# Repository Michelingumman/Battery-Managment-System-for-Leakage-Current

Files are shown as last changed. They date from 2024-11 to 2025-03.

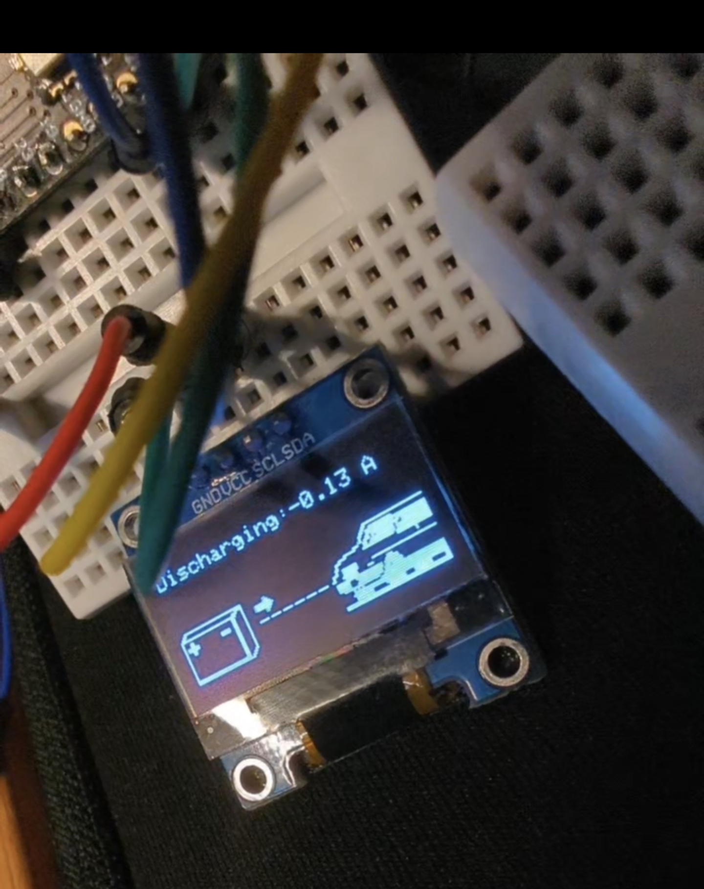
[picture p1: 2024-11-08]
rapport/screen.png

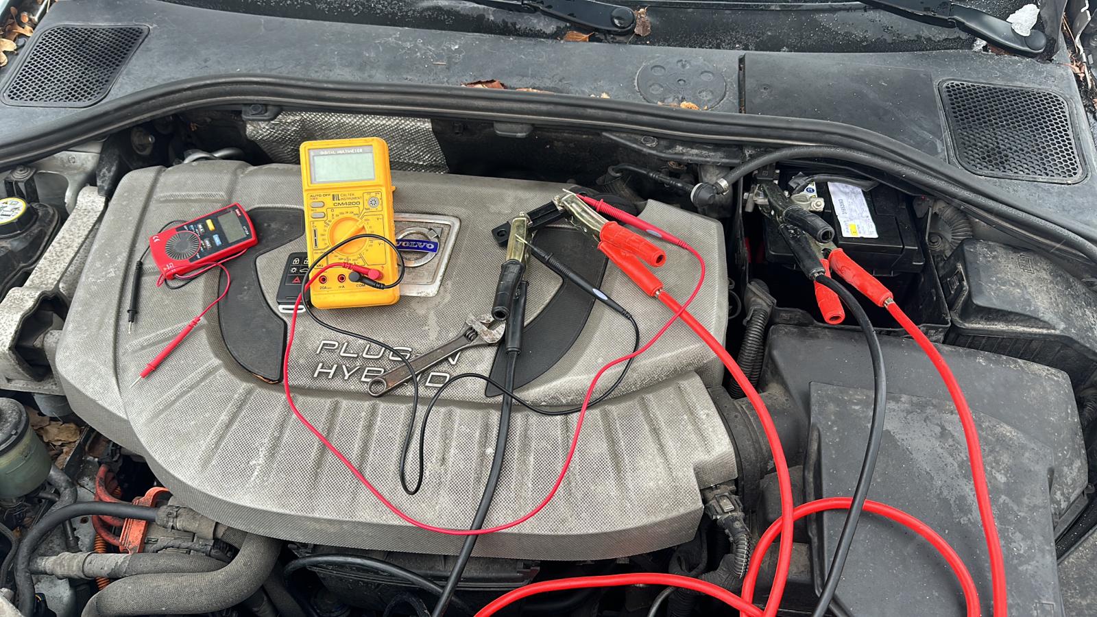
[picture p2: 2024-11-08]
rapport/test-setup.jpg

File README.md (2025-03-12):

<div align="center">
  <h1>🔋 ESP32 Battery Management System 🔌</h1>
  <p><em>A comprehensive solution for monitoring battery performance with wireless connectivity, data logging, and real-time analysis</em></p>

  <p>
    
    
    
    
  </p>
</div>

<div align="center">
  <table>
    <tr>
      <td width="70%">
        MQTT Dashboard
        <p align="center"><strong>MQTT Dashboard</strong> - Real-time monitoring</p>
      </td>
      <td width="50%">
        System Overview
        <p align="center"><strong>Added Display</strong> - Intuative animation</p>
      </td>
    </tr>
  </table>
</div>

<p align="center">
  OLED Display
  <br>
  <em>Plotted data</em>
</p>
<p align="center">
  OLED Display
  <br>
  <em>Web UI for accessing local SD card with delete and download availability</em>
</p>

---

## ✨ Features

- **📊 High-Precision Measurements**: Uses ADS1115 16-bit ADC for accurate voltage and current readings
- **💾 Data Logging**: Automatically records measurements to SD card with timestamps
- **🌐 Enhanced Web Interface**: Access, view, and manage data files with improved file browser and deletion capabilities
- **📡 Real-Time MQTT**: Publishes data points to MQTT broker for remote monitoring
- **🔄 OTA Updates**: Update firmware wirelessly through web interface
- **📱 Optional Display**: OLED display support for direct status viewing (configurable)

## 🛠️ Hardware Requirements

<div align="center">
  <table>
    <tr>
      <td align="center"><b>Component</b></td>
      <td align="center"><b>Purpose</b></td>
    </tr>
    <tr>
      <td>ESP32 Development Board</td>
      <td>Main controller with WiFi capability</td>
    </tr>
    <tr>
      <td>ADS1115 16-bit ADC Module</td>
      <td>High-precision analog-to-digital conversion</td>
    </tr>
    <tr>
      <td>DS3231 RTC Module</td>
      <td>Accurate timestamping of measurements</td>
    </tr>
    <tr>
      <td>SD Card Module</td>
      <td>Data storage and logging</td>
    </tr>
    <tr>
      <td>Current Shunt (100A/75mV)</td>
      <td>Current measurement</td>
    </tr>
    <tr>
      <td>SSD1306 OLED Display (Optional)</td>
      <td>Real-time data visualization</td>
    </tr>
  </table>
</div>

## 📚 Software Dependencies

- **Arduino IDE** with ESP32 support
- **Libraries**:
  - `WiFi`, `AsyncTCP`, `ESPAsyncWebServer` - Network connectivity
  - `SdFat` - SD card file operations
  - `RTClib` - RTC module interface
  - `Adafruit_ADS1X15` - ADC interface
  - `PubSubClient` - MQTT functionality
  - `ElegantOTA` - Over-the-air updates
  - `Adafruit_GFX` and `Adafruit_SSD1306` - Display support (if enabled)

## 🚀 Setup

1. **Create a `secrets.h` file** with your credentials:
   ```cpp
   #define WIFI_SSID "your_wifi_ssid"
   #define WIFI_PASS "your_wifi_password"
   #define MQTT_SERVER "your_mqtt_broker_address"
   #define MQTT_PORT 1883
   #define MQTT_USER "your_mqtt_username"
   #define MQTT_PASS "your_mqtt_password"
   ```

2. **Connect hardware components** according to pinout defined in code
3. **Upload the firmware** to ESP32

## 📖 Usage

### 📊 Data Collection
- The system automatically logs current and voltage data to SD card
- Data files are named `Amps YYYY-MM-DD.txt` and `Volts YYYY-MM-DD.txt`
- Each line contains timestamped measurements in the format `HH:MM:SS --> value1, value2, ...`

### 🌐 Improved Web Interface
1. Connect to the same WiFi network as ESP32
2. Navigate to `http://<ESP32_IP_ADDRESS>/` to access the file browser
3. Features:
   - **View Files**: Click the "View" button to see file contents directly in browser
   - **Delete Files**: Safely remove files with confirmation dialog
   - **Directory Navigation**: Browse folders with intuitive path display
   - **File Information**: See file sizes in human-readable format
   - **Quick Access**: One-click access to OTA updates with prominent button
4. Access OTA update page at `http://<ESP32_IP_ADDRESS>/update`

### 📡 MQTT Monitoring
The system publishes to three MQTT topics:

1. `battery/data/current` - Real-time current measurements
2. `battery/data/voltage` - Real-time voltage measurements 
3. `battery/status` - Connection status with device IP address

Message format (JSON):
```json
{
  "timestamp": "2024-06-03 14:35:22",
  "current": 0.123,
  "voltage": 12.45
}
```

## ⚙️ Configuration

Key parameters can be adjusted in the code:
- WiFi reconnection interval
- MQTT topic names
- Display settings
- SD card pins

## 📄 License

MIT License

## 🙏 Acknowledgments

- Thanks to all libraries and their contributors
- Inspired by various battery monitoring projects

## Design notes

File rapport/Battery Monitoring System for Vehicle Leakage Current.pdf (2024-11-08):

# Battery Monitoring System for Vehicle Leakage Current

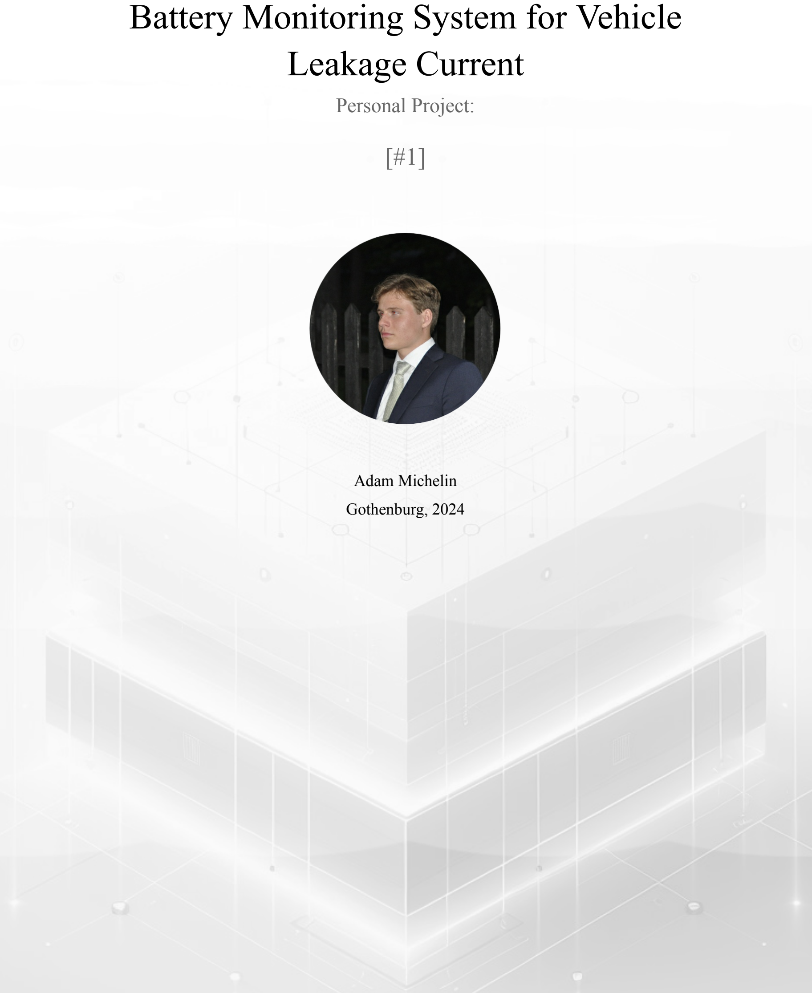
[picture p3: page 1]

### Personal Project:

[#1]

Adam Michelin
Gothenburg, 2024

## Abstract

The Battery Monitoring System (BMS) developed for monitoring vehicle leakage current presents a promising solution to the challenges of unexpected battery discharging. This report outlines the development process, including the rationale, methodology, components used, and measurement principles. Results from initial tests, along with discussions on the system's effectiveness and comparisons with other diagnostics tools, are provided. The report concludes with recommendations for future improvements and the significance of this project as a prototype for troubleshooting automotive electrical issues. It is worth noting that this project is a proof of concept undertaken for personal interest, aimed at enhancing understanding in electrical engineering and broadening personal project experiences.

## 1. Introduction

Upon encountering repeated instances of the starter battery in a family member's car being depleted after just 2 days of non-use, the need to investigate and rectify the underlying cause became paramount. Despite seeking assistance from a reputable service center, the persistent issue of unexplained and continuous battery discharge remained unresolved.

The starter battery, with a capacity of approximately 70Ah, should ideally hold a charge for at least some weeks under normal conditions. However, its complete depletion within 48 hours indicates an average draw of about 1.5 Amperes, meaning a persistent and unexplained drain on the system is occurring when the car is left unused.

Facing these challenges and the limitations of help from the service center, a proactive fix was developed: a Battery Monitoring System (BMS). This electrical device, designed to be compact, does a few key things. It keeps an eye on how much current the battery is using both the charging and discharging cycles, stores that data, and then shows it visually for analysis. The idea is to track the power usage over time in different situations and environments, hoping to find out why the battery keeps draining. This data-driven approach not only helps the troubleshooting but also gives solid evidence to explore new strategies if the usual fixes don't do the trick.

## 2. Material & Method

### 2.1 Vehicle and Battery Information

The vehicle under study is a "Volvo V60 D6 Plug-in Hybrid 2013" equipped with a 70Ah starter battery.

### 2.2 Components Used

The measurement device comprises the following components:
- ESP32 (WEMOS LOLIN D32, Espressif).
- DS3231 module (Real Time Clock).
- SD card reader module (SPI communication).
- Adafruit ADS1115 (16bit, Analog-Digital-Converter module).
- Shunt Resistor (75mV = 50A).
- Adafruit_SSD1306 (128x64 OLED display)

### 2.3 Libraries and Programming:

The necessary libraries for ESP32 programming include:

- Arduino.h
- Wire.h
- Adafruit_GFX
- Adafruit_SSD1306.h
- image_data.h (custom library)
- SPI.h
- SdFAT.h
- RTClib.h
- string.h

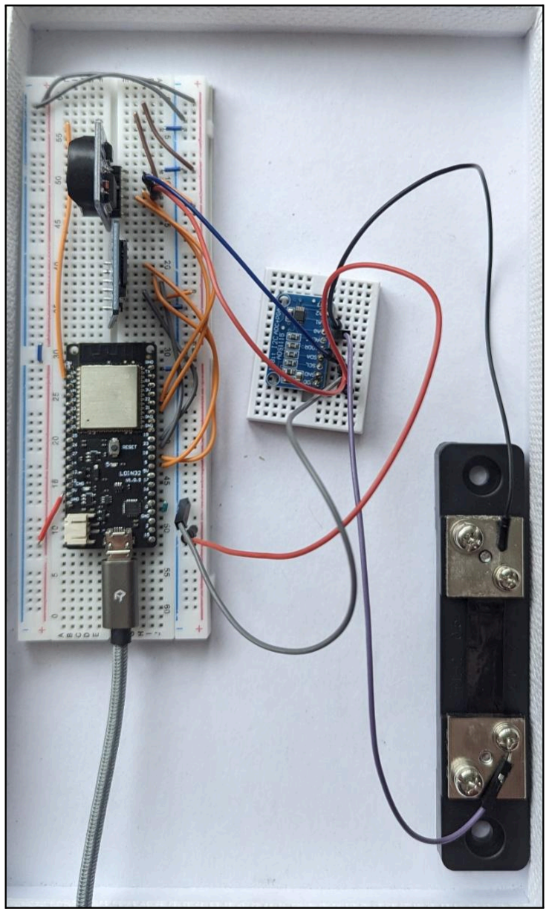
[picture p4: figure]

- Adafruit_ADS1X15.h | Figure 1, prototype on breadboard

The ESP32 was programmed using PlatformIO in Microsoft's Visual Studio Code (VS Code), enabling board configuration, programming, and debugging for various microcontrollers.

### 2.4 Electrical Setup:

The electrical circuit was initially prototyped on a breadboard for ease of debugging and testing flexibility with other modules. The final product remains on a breadboard but may transition to a custom PCB or other form based on the owner's preferences.

### 2.5 Measurement Principle:

The measurement device primarily monitors the voltage drop across the shunt resistor, which is strategically low in resistance to minimize its impact on the car's battery circuit and current flow. This voltage drop is measured and amplified through a 16-bit ADC for enhanced resolution. Without the 16-bit ADC, the voltage would be converted via the built in 12-bit ADC on the ESP32. The current resolution would then be too low, measuring steps of only 12mA, changing to a 16-bit ADC gives us the resolution of 0.7mA which is subjectively chosen to measure even the smallest current changes to better understand the underlying problem to the discharging.

### 2.6 Data Collection and Analysis:

The ESP32, with the assistance of the RTC and SD card reader, stores voltage readings every second and converts them into actual current values based on the calculated resolution. This data is then organized into minute-based arrays and stored on the SD card for further analysis. A Python script is used for visualizing this data in graph format, aiding in the interpretation of battery current over time.

## 3.Results

### 3.1 First Graph of Monitored Battery System

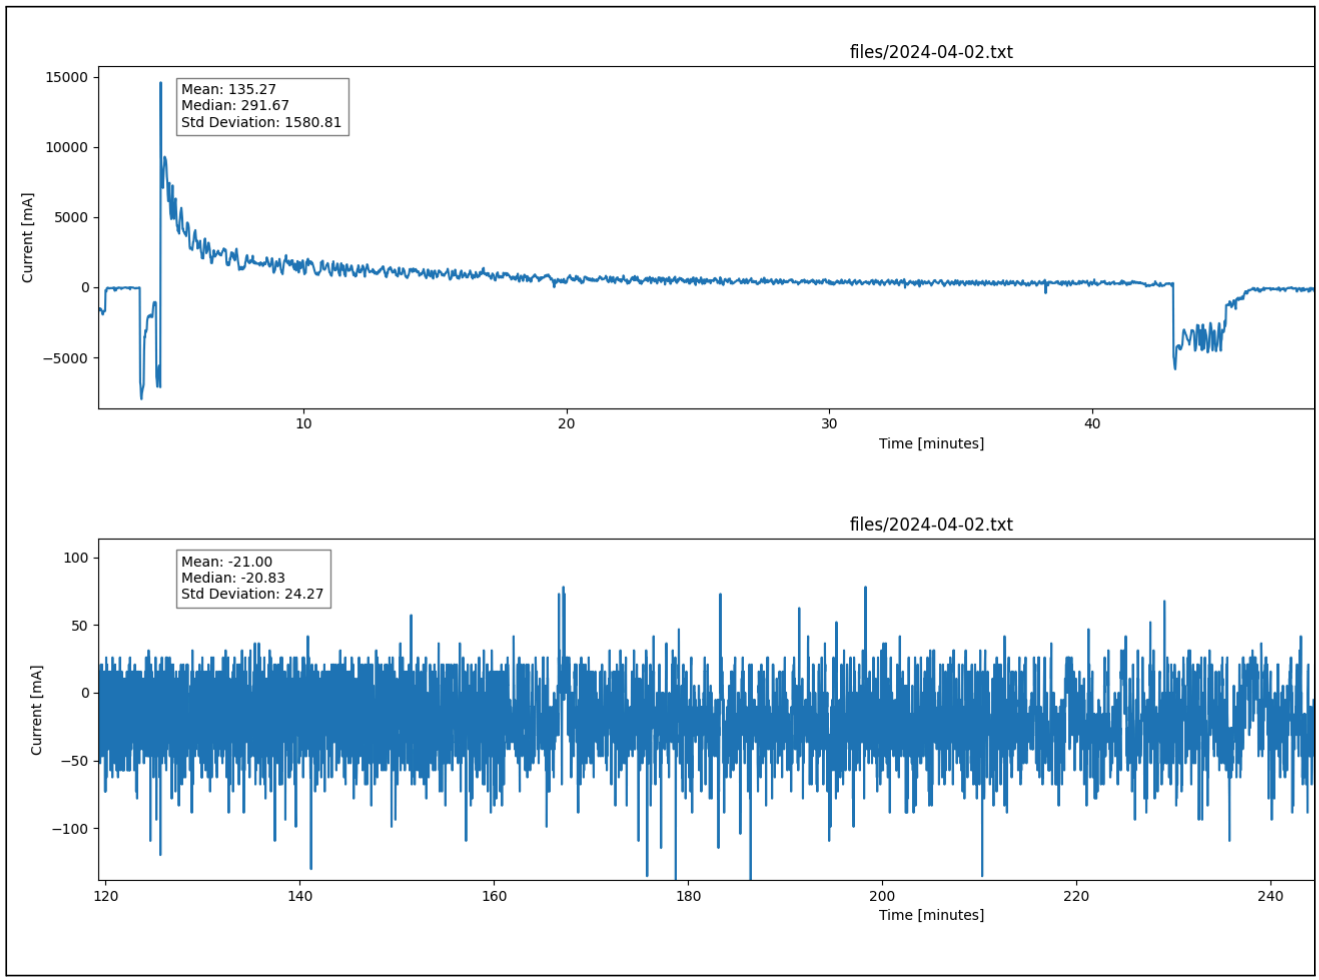
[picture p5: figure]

Figure 2, first test run

### 3.2 Simplified Circuit

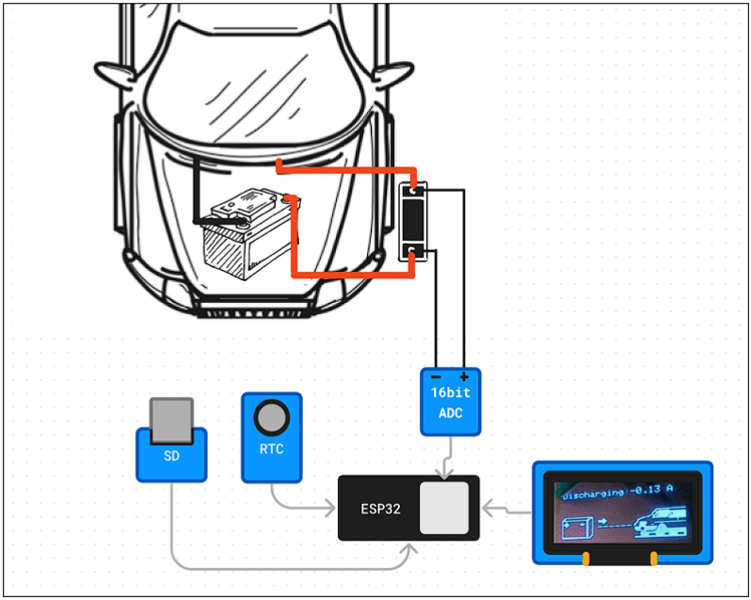
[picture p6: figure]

Figure 3, simplified circuit of the finished device

## 4. Discussion

### 4.1 Battery Discharge Analysis

Since the device only ran a single test lasting a few hours before the making of this report, we haven't yet identified a solution to the issue of unwanted discharging. As we conduct more experiments and analyze the data, we will update this report with our findings.

Regarding the device's performance, it met our expectations. The graphs generated are clear, showing the precise measured current at each timestamp.

### 4.2 Effectiveness of Monitoring System

The Battery Monitoring System (BMS) has proven highly effective due to its user-friendly design, clear display, and intuitive operation, which have laid a solid foundation for troubleshooting current leakage in the car.

The device's functionality includes the ability to measure both positive and negative voltages across the shunt resistor, thanks to the 16-bit ADC. Initially, the project involved integrating an amplifier and offset circuit to handle negative voltages shown in figure 4 & 5. This would firstly offset the maximum negative voltage (-75mV) to 0V, then amplify the signal to 5V as maximum positive voltage (the ESP32's maximum input voltage). As a result, the signal is converted to a range of 0-2.5V, where negative voltages represent current flow from the battery (drawn current) and positive voltages represent current charging the battery. This approach would enhance the device's usability and makes interpreting the data more intuitive for users if not an ADC with negative input voltage would have been used.

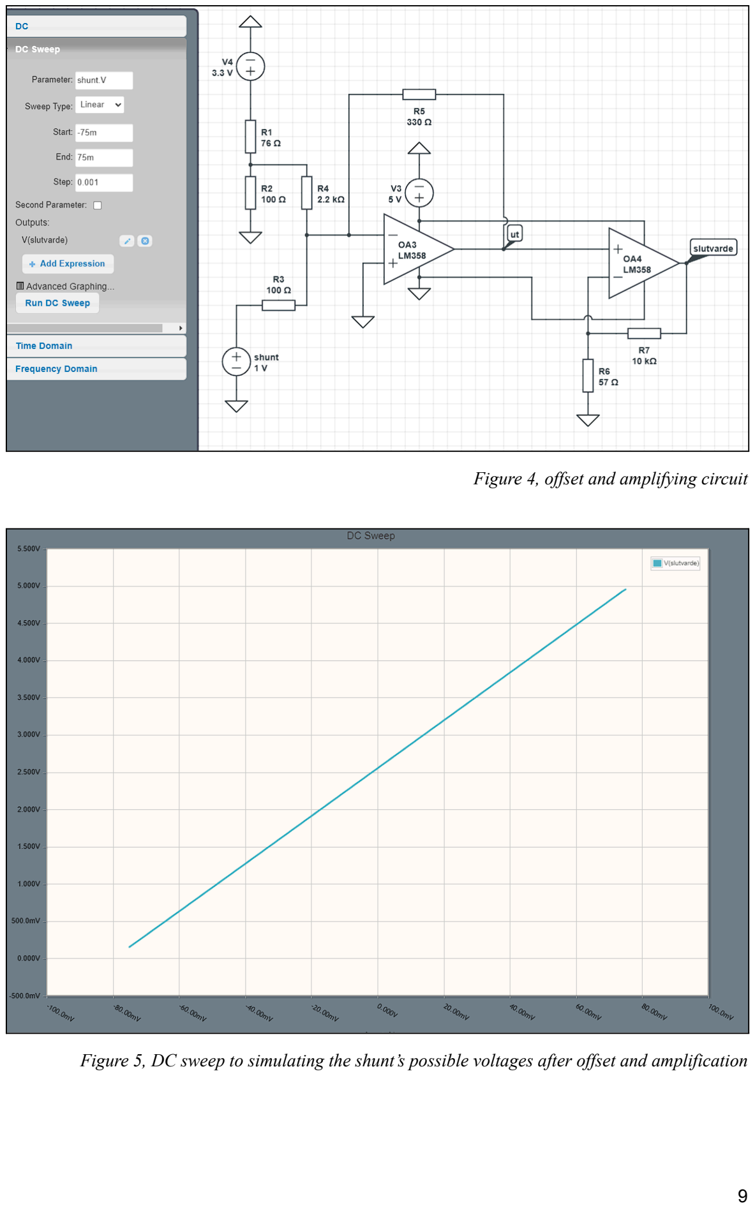
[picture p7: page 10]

Figure 4, of set and amplifying circuit

Figure 5, DC sweep to simulating the shunt’s possible voltages after of set and amplification

### 4.3 Comparison with Other Diagnostics

When troubleshooting battery failures or anomalies, several techniques and devices can be used alongside or in comparison to a Battery Monitoring System (BMS). Here are some common ones and how they compare to the developed device describes in this report.

4.3.1 Onboard Diagnostics (OBD) Scanner
OBD scanners are commonly used to connect to a vehicle's onboard diagnostics system, offering insights into error codes, system parameters, and electronic issues. While OBD scanners excel in providing a broad overview of a vehicle's health and diagnosing common electronic problems, they may lack the specificity needed for detailed battery monitoring. Unlike the BMS developed in this report, OBD scanners may not directly measure battery current draw or provide real-time data on charge/discharge cycles.

4.3.2 Advanced Battery Management System (ABMS)
Advanced Battery Management Systems, akin to the BMS described in this report, offer comprehensive monitoring of battery health, temperature, and charge/discharge cycles. They are particularly effective in electric vehicles and renewable energy systems. ABMSs often integrate sophisticated algorithms and sensor arrays to optimize battery performance and prolong lifespan. Compared to traditional BMS setups, the developed BMS in this report focuses specifically on measuring current draw and providing detailed data visualization, which can be advantageous for pinpointing discharge anomalies. Since the troubled car described in this report does not have an ABMS installed, and considering the technical complexities and high costs associated with such a system, it is not deemed suitable for addressing the specific problem that our Battery Monitoring System (BMS) aims to solve.

4.3.3 Thermal Imaging
Thermal imaging utilizes infrared technology to detect hotspots or abnormal temperature distributions in batteries, signaling potential issues such as internal shorts or cell degradation. While thermal imaging is very suitable for identifying thermal irregularities, it primarily focuses on temperature variations and may not directly measure electrical parameters like current draw or voltage. Therefore, while complementary to the BMS, thermal imaging alone may not provide the complete picture necessary for diagnosing complex electrical issues related to battery discharge. Moreover, identifying the suspected fault in this situation as its highly likely a component error within the car's diverse set of components makes implementing thermal imaging challenging for pinpointing such faults on a large scale.

4.3.4 Circuit Analysis Tools
Circuit analysis tools, including oscilloscopes and power analyzers, are crucial for assessing electrical circuits' integrity and identifying faults related to battery operation. These tools offer detailed insights into voltage waveforms, current fluctuations, and circuit behavior. However, they typically require specialized expertise to interpret results effectively and may not offer the continuous monitoring capabilities of a dedicated BMS. The BMS developed in this report focuses on continuous, real-time monitoring of battery current draw and provides visual data representation for ease of analysis, which may be more user-friendly compared to complex circuit analysis tools.

### 4.4 Future Improvements and Recommendations

4.4.1 Enhanced Data Logging
Implementing more advanced data logging capabilities, such as storing additional parameters like temperature, voltage ripples and compensation for noise, can provide a more comprehensive understanding of the battery's behavior and health. This data can be instrumental in identifying patterns or correlations that may contribute to battery discharge issues.

4.4.2 Real-Time Alerts
Real-Time Alerts: Introducing real-time alerting mechanisms based on predefined thresholds for current draw or voltage levels can notify users of potential anomalies as they occur. This proactive approach can help in early detection and prompt action to prevent further battery damage or vehicle downtime.

4.4.3 Remote Monitoring and Control
Incorporating remote monitoring and control features can enable users to access BMS data and settings remotely. This can be particularly beneficial for service technicians, allowing them to monitor multiple vehicles' battery health and take proactive measures as needed. Initially, the project envisioned utilizing the ESP32's WiFi module to transmit data when the vehicle is parked at home, automatically connecting to the home WiFi network and identifying unsent data for remote monitoring. This functionality was planned to significantly enhance the BMS's usability but was ultimately postponed due to time constraints.

## 5. Conclusion

The Battery Monitoring System (BMS) developed for vehicle leakage current presents a promising solution to the challenges of unexpected battery discharging. Despite being a prototype, it effectively monitors the vehicles current from the starter battery and provides valuable insights through data visualization.

This project, born out of a personal need, has not only showcased practical application but also provided a valuable learning experience as an electrical engineering student at Chalmers University.

Moving forward, enhancements like advanced data logging, real-time alerts, and remote monitoring features can further improve the BMS's functionality. Collaborative efforts and continuous testing will be key to refining and validating the battery system.

Despite constraints faced during development, the BMS prototype represents a significant step towards leveraging technology for automotive diagnostics and highlights the potential for future advancements in this field.

## 6. Appendix

### 6.1 ESP32 Main Source Code

#include <Arduino.h>

#include <Wire.h>

#include <Adafruit_GFX.h>

#include <Adafruit_SSD1306.h> #include "image_data.h"

#include <SPI.h>

#include <SdFat.h>

#include <RTClib.h>

#include <string.h>

#include <Adafruit_ADS1X15.h>

//#include <DS3231.h>

// change this value depending on the shunt used #define SHUNT_SIZE 50 //amps / 75mV

#define SCREEN_WIDTH 128 // OLED display width, in pixels #define SCREEN_HEIGHT 64 // OLED display height, in pixels #define LEFT 1

#define RIGHT 0

#define INPUT_PIN 32

// Declaration for an SSD1306 display connected to I2C (SDA, SCL pins) // The pins for I2C are defined by the Wire-library.
// On Wemos Lolin32 GPIO21(SDA), GPI022(SCL)

//setup and class for ADC
Adafruit_ADS1115 ads; /* Use this for the 16-bit version */ //Adafruit_ADS1015 ads; /* Use this for the 12-bit version */

// RTC DS3231 module

//class declraration
RTC_DS3231 rtc;
//DS3231 rtc(SDA, SCL);

// SD-card reader
SdFat sd;
SdFile file;
// Change this to the actual pin used for chip select const int chipSelect = 5;

#define OLED_RESET -1 // Reset pin # (or -1 if sharing Arduino reset pin)

#define SCREEN_ADDRESS 0x3C ///< See datasheet for Address; 0x3D for 128x64, 0x3C for 128x32

Adafruit_SSD1306 display(SCREEN_WIDTH, SCREEN_HEIGHT, &Wire, OLED_RESET);

/// @brief ////////FUNCTION DECLARATION /////////////
void write_file(float data, int count);
float get_adc_data();
void interface(float amps, int dir);
void move_arrow(int dir, float amps); /// @brief //////////////////////////////////////////

void setup() {

Serial.begin(115200);
while (!Serial) {} // wait for board
// SSD1306_SWITCHCAPVCC = generate display voltage from 3.3V internally // Uncomment to use display
if(!display.begin(SSD1306_SWITCHCAPVCC, SCREEN_ADDRESS)) { Serial.println(F("SSD1306 allocation failed"));
for(;;); // Don't proceed, loop forever
} else {
Serial.println("SSD1306 allocation success"); }

// Clear the buffer

display.clearDisplay();

set analog pin GPIO4 to input to read pinMode(INPUT, INPUT);

// Ported to SdFat from the native Arduino SD library example by Bill Greiman // On the Ethernet Shield, CS is pin 4. SdFat handles setting SS
/*
SD card read/write

This example shows how to read and write data to and from an SD card file The circuit:
* SD card attached to SPI bus as follows:
** MOSI - pin 11
** MISO - pin 12
** CLK - pin 13
** CS - pin 4

created Nov 2010
by David A. Mellis
updated 2 Dec 2010
by Tom Igoe
modified by Bill Greiman 11 Apr 2011 This example code is in the public domain.

*/

// setup code for ADC
// The ADC input range (or gain) can be changed via the following // functions, but be careful never to exceed VDD +0.3V max, or to // exceed the upper and lower limits if you adjust the input range! // Setting these values incorrectly may destroy your ADC!
// | ADS1015 ADS1115
// | ------- -------
// ads.setGain(GAIN_TWOTHIRDS); // 2/3x gain +/- 6.144V 1 bit = 3mV | 0.1875mV
(default)
// ads.setGain(GAIN_ONE); | // 1x gain +/- 4.096V 1 bit = 2mV | 0.125mV

// ads.setGain(GAIN_TWO); | // 2x gain +/- 2.048V 1 bit = 1mV | 0.0625mV
// ads.setGain(GAIN_FOUR); | // 4x gain +/- 1.024V 1 bit = 0.5mV 0.03125mV
// ads.setGain(GAIN_EIGHT); | // 8x gain +/- 0.512V 1 bit = 0.25mV 0.015625mV
ads.setGain(GAIN_SIXTEEN); // 16x gain +/- 0.256V 1 bit = 0.125mV 0.0078125mV

if (!ads.begin()) {
Serial.println("Failed to initialize ADS.");
while (1);
}

// RTC setup
rtc.begin();
// if (! rtc.begin()) {
// Serial.println("Couldn't find RTC"); // Serial.flush();
// while (1) delay(10);
// }
// //gets the time when compiled
// rtc.adjust(DateTime(F(__DATE__), F(__TIME__)));

// SD card setup

// Initialize SdFat or print a detailed error message and halt // Use half speed like the native library.
// change to SPI_FULL_SPEED for more performance.
if (!sd.begin(chipSelect, SPI_HALF_SPEED)) sd.initErrorHalt();

}

// // Code for SD card
// // Initialize SD card
// if (!SD.begin(5)) {
// Serial.println("SD card initialization failed!");

// return;
// }
// Serial.println("SD card initialized successfully!");

// >Variables
float current = 0.0;
int direction = RIGHT;
int direction_before = LEFT; int direct_log = 0;
int count = 0;

void loop() {

while(count < 60){
float data = get_adc_data(); Serial.println(data);
// write to file
write_file(data, count);

delay(999.96); //compensating for runtime count++;
}

count = 0;

// code for display")
// Uncomment to use with display current = analogRead(INPUT_PIN); direct_log = analogRead(INPUT_PIN); Serial.println(direct_log);

current = ((current * 200)/(1<<16)) - 12;
// this means that the voltage is negative
if(current < 0) direction = RIGHT; // which means that the direction of current is charging the battery

else if(current >= 0) direction = LEFT; // which means that the direction of current is

discharging the battery

//Serial.println(direction) //Serial.println(current);

interface(current, direction);

// Serial.println(current)
}

float get_adc_data(){
int16_t data;
float multiplier = 0.0078125F; /* ADS1115 @ +/- 6.144V gain (16-bit results) */ int results = ads.readADC_Differential_0_1();
return (results * multiplier * SHUNT_SIZE / 75 * 1000);
}

void write_file(float data, int count) {
DateTime time = rtc.now();

String date = time.timestamp(DateTime::TIMESTAMP_DATE); String txt = ".txt";
String filename_merged = date + txt;
// Convert filnamn to a char*
char filename[filename_merged.length() + 1]; // +1 for null terminator filename_merged.toCharArray(filename, sizeof(filename));

// Serial.println(date);
// open the file for write at end like the Native SD library
if (!file.open(filename, O_RDWR | O_CREAT | O_AT_END)) sd.errorHalt("opening file for write
failed");

if(count==0){

file.println();
file.print(time.timestamp(DateTime::TIMESTAMP_TIME)); file.print(" --> ");
}

if(count < 59){
file.print(data);
file.print(", "); // Add a collon between elements }

if(count == 59) file.println();
// close the file:
file.close();

}

void interface(float amps, int dir){
//dir is either LEFT or RI display.clearDisplay();
display.drawLine(41, 46, 45, 46, WHITE); display.drawLine(65, 46, 69, 46, WHITE); display.drawLine(71, 46, 75, 46, WHITE); display.drawLine(59, 46, 63, 46, WHITE); display.drawLine(53, 46, 57, 46, WHITE);
display.drawLine(47, 46, 51, 46, WHITE);
display.drawBitmap(79, 16, image_volvo_bits, 50, 50, WHITE); display.drawBitmap(78, 30, image_Layer_18_bits, 51, 17, WHITE); display.drawBitmap(0, 31, image_battery__2__bits, 40, 30, WHITE); move_arrow(dir, amps);
display.display();
}

// function that moves the arrow either right or left showing the current direction

// this function below should be able to be run in the background of the code void move_arrow(int dir, float amps){
int x = 38;
int x_slut = 69;

if(dir == RIGHT){
x = 38;
display.setTextColor(WHITE); display.setTextSize(1);
display.setCursor(3, 6);
display.setTextWrap(false); display.print("Discharging:"); display.print(amps);
display.print(" A");
for(int i = 0; i < 31; i++){
display.drawBitmap(x, 37, image_Pin_arrow_right_9x7_bits, 9, 7, WHITE); display.display();
delay(10);
display.drawBitmap(x, 37, image_Pin_arrow_right_9x7_bits, 9, 7, BLACK); x++;
if(x==x_slut) x = 38;
}
}

else if(dir == LEFT){
x = x_slut;
display.setTextColor(WHITE); display.setTextSize(1);
display.setCursor(3, 6);
display.setTextWrap(false); display.print("Charging:"); display.print(amps);
display.print(" A");
for(int i = 0; i < 31; i++){
display.drawBitmap(x, 37, image_Pin_arrow_left_9x7_bits, 9, 7, WHITE); display.display();
delay(10);
display.drawBitmap(x, 37, image_Pin_arrow_left_9x7_bits, 9, 7, BLACK);

x--;
if(x==38) x = x_slut;
}
}
}

## 6.2 Python Code for Visualization

import matplotlib.pyplot as plt
import datetime

# Define a function to read the file and extract the data def read_file(file_name):

with open(file_name, 'r') as file:
lines = file.readlines()
data = []
for line in lines:
if '-->' in line:
numbers_part = line.split('-->')[-1] numbers = [float(x) for x in numbers_part.strip().split(',') if x] data.extend(numbers)
return data

# Define a function to plot the data def plot_data(data):

plt.plot(range(len(data)), data) plt.xlabel('Time (seconds)') plt.ylabel('Data')
plt.title('Data over Time') plt.show()

# Get today's date

today = datetime.date.today()

# Format the date as a string in the format 'YYYY-MM-DD' today_str = today.strftime('%Y-%m-%d')

# Define the file name

file_name = f'files/{today_str}.txt'

# Main code

# Read the file and extract the data data = read_file(file_name) print(data)

# Plot the data

plot_data(data)

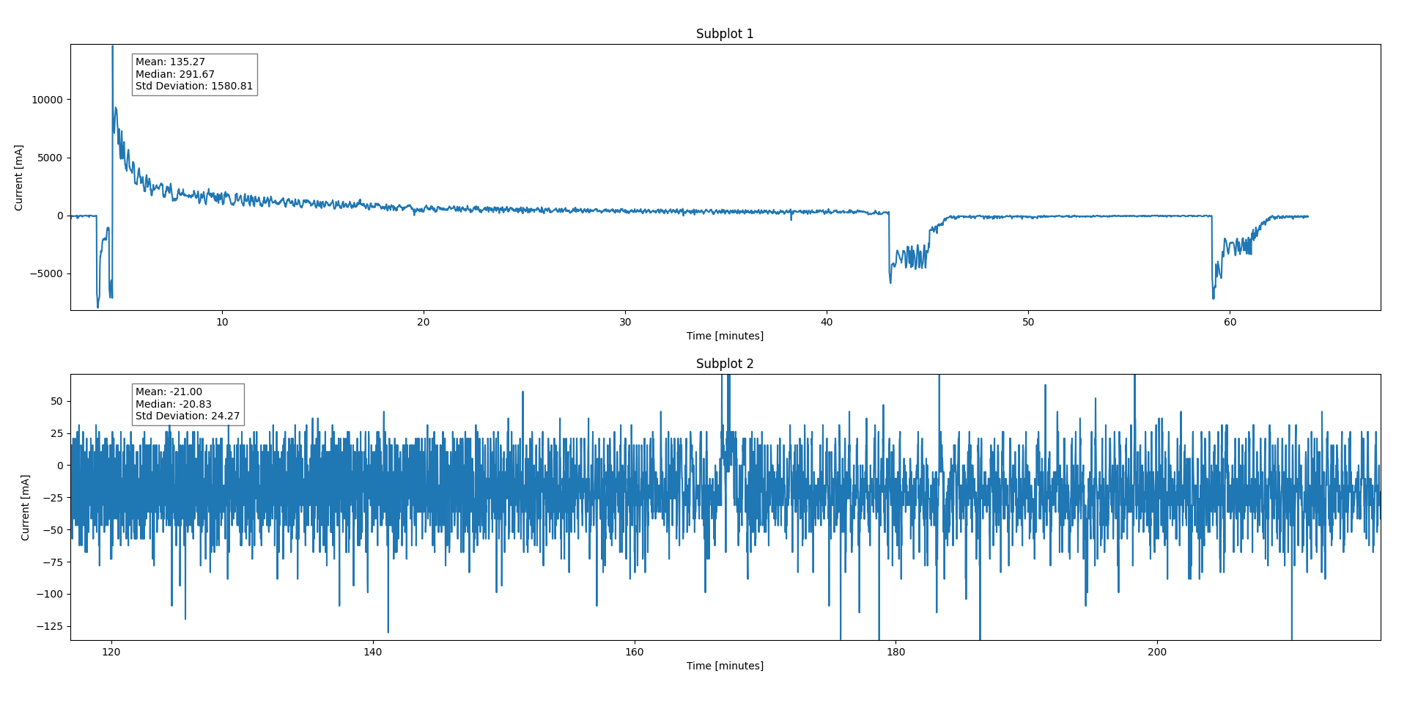
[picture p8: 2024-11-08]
rapport/data_log_01-02.png

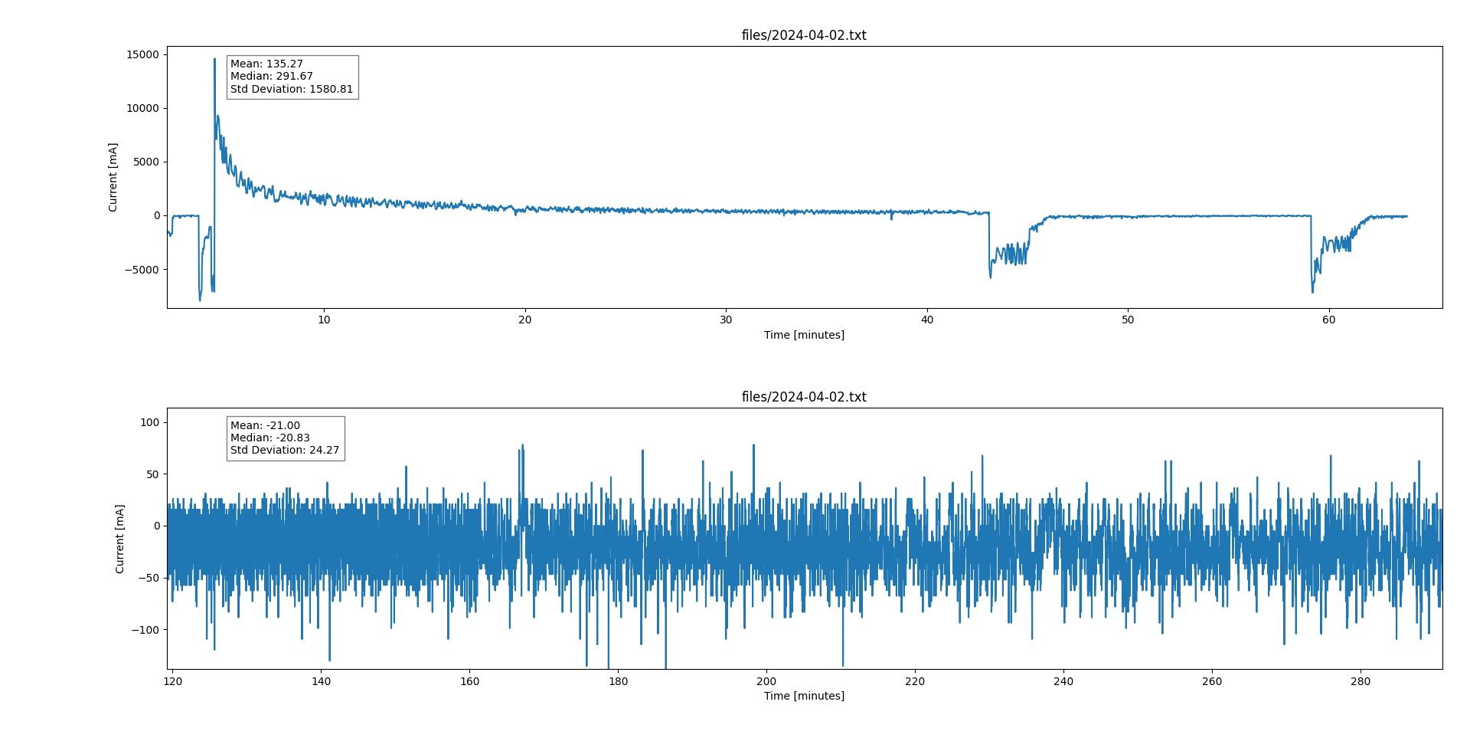
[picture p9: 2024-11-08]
rapport/data_log_01-03.png

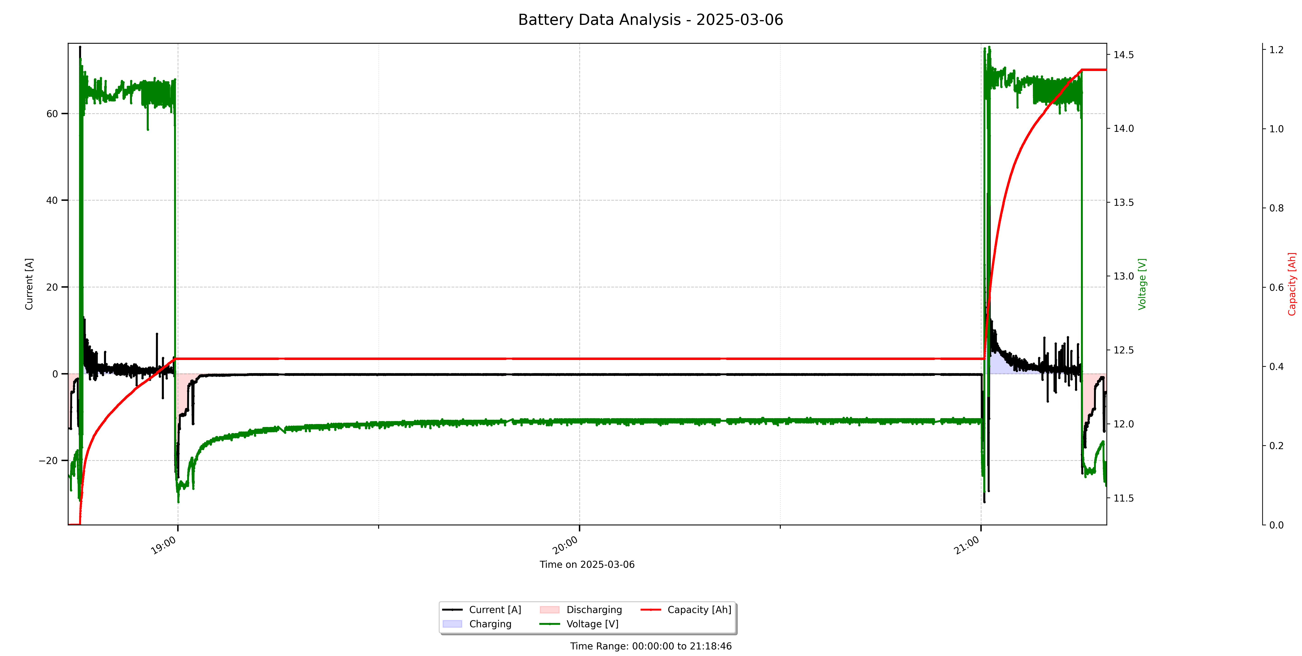
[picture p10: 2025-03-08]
visualization/plots/battery_data_2025-03-06.png

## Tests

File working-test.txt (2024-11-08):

#include <Arduino.h>
#include <Wire.h>
#include <Adafruit_GFX.h>
#include <Adafruit_SSD1306.h>
#include "image_data.h"
#include <SPI.h>
#include <SdFat.h>

#define SCREEN_WIDTH 128 // OLED display width, in pixels
#define SCREEN_HEIGHT 64 // OLED display height, in pixels
#define LEFT 1
#define RIGHT 0

#define INPUT_PIN 32
// Declaration for an SSD1306 display connected to I2C (SDA, SCL pins)
// The pins for I2C are defined by the Wire-library. 
// On Wemos Lolin32 GPIO21(SDA), GPI022(SCL)

// Change this to the actual pin used for chip select

#define OLED_RESET     -1 // Reset pin # (or -1 if sharing Arduino reset pin)
#define SCREEN_ADDRESS 0x3C ///< See datasheet for Address; 0x3D for 128x64, 0x3C for 128x32
Adafruit_SSD1306 display(SCREEN_WIDTH, SCREEN_HEIGHT, &Wire, OLED_RESET);

/// @brief ////////FUNCTION DECLARATION /////////////
void interface(float amps, int dir);
void move_arrow(int dir, float amps);
/// @brief //////////////////////////////////////////

void setup() {

  // SSD1306_SWITCHCAPVCC = generate display voltage from 3.3V internally
  // // Uncomment to use display
  // if(!display.begin(SSD1306_SWITCHCAPVCC, SCREEN_ADDRESS)) {
  //   Serial.println(F("SSD1306 allocation failed"));
  //   for(;;); // Don't proceed, loop forever
  // } else {
  //   Serial.println("SSD1306 allocation success");
  // }

  // // Clear the buffer
  // display.clearDisplay();

  // set analog pin GPIO4 to input to read
  //pinMode(INPUT, INPUT);

// Ported to SdFat from the native Arduino SD library example by Bill Greiman
// On the Ethernet Shield, CS is pin 4. SdFat handles setting SS
const int chipSelect = 5;
/*
 SD card read/write
  
 This example shows how to read and write data to and from an SD card file 	
 The circuit:
 * SD card attached to SPI bus as follows:
 ** MOSI - pin 11
 ** MISO - pin 12
 ** CLK - pin 13
 ** CS - pin 4
 
 created   Nov 2010
 by David A. Mellis
 updated 2 Dec 2010
 by Tom Igoe
 modified by Bill Greiman 11 Apr 2011
 This example code is in the public domain.
 	 
 */
SdFat sd;
SdFile myFile;

  Serial.begin(9600);
  while (!Serial) {}  // wait for Leonardo
  Serial.println("Type any character to start");
  while (Serial.read() <= 0) {}
  delay(400);  // catch Due reset problem
  
  // Initialize SdFat or print a detailed error message and halt
  // Use half speed like the native library.
  // change to SPI_FULL_SPEED for more performance.
  if (!sd.begin(chipSelect, SPI_HALF_SPEED)) sd.initErrorHalt();

  // open the file for write at end like the Native SD library
  if (!myFile.open("test.txt", O_RDWR | O_CREAT | O_AT_END)) {
    sd.errorHalt("opening test.txt for write failed");
  }
  // if the file opened okay, write to it:
  Serial.print("Writing to test.txt...");
  myFile.println("testing 1, 2, 3.");

  // close the file:
  myFile.close();
  Serial.println("done.");

  // re-open the file for reading:
  if (!myFile.open("test.txt", O_READ)) {
    sd.errorHalt("opening test.txt for read failed");
  }
  Serial.println("test.txt:");

  // read from the file until there's nothing else in it:
  int data;
  while ((data = myFile.read()) >= 0) Serial.write(data);
  // close the file:
  myFile.close();
}

//  // Code for SD card
//  // Initialize SD card
//   if (!SD.begin(5)) {
//     Serial.println("SD card initialization failed!");
//     return;
//   }
//   Serial.println("SD card initialized successfully!");

float current = 0.0;
int direction = RIGHT;
int direction_before = LEFT;
int direct_log = 0;

void loop() {

  // Uncomment to use with display
  // code for SD card reading and writing
 
  // File32 file = SD.open("data-logger.txt", FILE_WRITE);
  // if (file) {
  //   file.println("OMG, det fungerade");
  //   file.close();
  //   Serial.println("Det borde funkat");
  // } else {
  //   for(;;);
  // }

  // // Uncomment to use with display
    // current = analogRead(INPUT_PIN);
    // direct_log = analogRead(INPUT_PIN);
    // Serial.println(direct_log);

    // current = ((current * 200)/4096) - 12;
    // // this means that the voltage is negative
    // if(current < 0) direction = RIGHT;   // which means that the direction of current is charging the battery
    
    // else if(current >= 0) direction = LEFT; // which means that the direction of current is discharging the battery

    // //Serial.println(direction)
    // //Serial.println(current);

    // interface(current, direction);

    // // Serial.println(current)
}

void interface(float amps, int dir){
  //dir is either LEFT or RI
  display.clearDisplay();
  display.drawLine(41, 46, 45, 46, WHITE);
  display.drawLine(65, 46, 69, 46, WHITE);
  display.drawLine(71, 46, 75, 46, WHITE);
  display.drawLine(59, 46, 63, 46, WHITE);
  display.drawLine(53, 46, 57, 46, WHITE);
  display.drawLine(47, 46, 51, 46, WHITE);
  display.drawBitmap(79, 16, image_volvo_bits, 50, 50, WHITE);
  display.drawBitmap(78, 30, image_Layer_18_bits, 51, 17, WHITE);
  display.drawBitmap(0, 31, image_battery__2__bits, 40, 30, WHITE);
  move_arrow(dir, amps);
  display.display();
}

// function that moves the arrow either right or left showing the current direction
// this function below should be able to be run in the background of the code
void move_arrow(int dir, float amps){
  int x = 38;
  int x_slut = 69;

  if(dir == RIGHT){
  x = 38;
    display.setTextColor(WHITE);
    display.setTextSize(1);
    display.setCursor(3, 6);
    display.setTextWrap(false);
    display.print("Discharging:");
    display.print(amps);
    display.print(" A");
    for(int i = 0; i < 31; i++){
      display.drawBitmap(x, 37, image_Pin_arrow_right_9x7_bits, 9, 7, WHITE);
      display.display();
      delay(10);
      display.drawBitmap(x, 37, image_Pin_arrow_right_9x7_bits, 9, 7, BLACK);
      x++;
      if(x==x_slut) x = 38;
    }
  }

  else if(dir == LEFT){
  x = x_slut;
    display.setTextColor(WHITE);
    display.setTextSize(1);
    display.setCursor(3, 6);
    display.setTextWrap(false);
    display.print("Charging:");
    display.print(amps);
    display.print(" A");
    for(int i = 0; i < 31; i++){
      display.drawBitmap(x, 37, image_Pin_arrow_left_9x7_bits, 9, 7, WHITE);
      display.display();
      delay(10);
      display.drawBitmap(x, 37, image_Pin_arrow_left_9x7_bits, 9, 7, BLACK);
      x--;
      if(x==38) x = x_slut;
    }
  }
}

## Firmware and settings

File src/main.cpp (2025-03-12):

/** CREATED BY ADAM AND MATTIAS MICHELIN in STHLM & Borås
 * 
 * Battery Management System for Leakage Current Monitoring
 * 
 * This ESP32-based system monitors battery voltage and current,
 * storing timestamped readings to SD card files for later analysis.
 * When WiFi connection is available, data can be accessed remotely.
 * 
 * Features:
 * - High-precision ADC measurements for voltage and current
 * - RTC-synchronized timestamps
 * - SD card data logging
 * - Web interface for accessing logged data files
 * - MQTT data upload when connected to WiFi
 * - OTA updates via WiFi
 * 
 * Hardware:
 * - ESP32 development board
 * - ADS1115 16-bit ADC
 * - DS3231 RTC module
 * - SD card module
 * - Current shunt (100A/75mV)
 */

// ===== FEATURE FLAGS =====
// Set to 1 to enable display support, 0 to disable
#define ENABLE_DISPLAY 0
// Set to 1 to enable MQTT data upload, 0 to disable
#define ENABLE_MQTT 1
// Set to 1 to enable SD card testing mode (writes test data every second)
#define SD_CARD_TEST_MODE 0

#define UPDATE_RTC_TIME 0

#define VOLTAGE_OFFSET 0.4
#define CURRENT_OFFSET 0.0

// Define LED_BUILTIN for ESP32 (usually GPIO2)
#define LED_BUILTIN 2

// ===== INCLUDE LIBRARIES =====
#include <Arduino.h>
#include <Wire.h>
#include "secrets.h"        // Contains WiFi credentials (WIFI_SSID, WIFI_PASS) and MQTT details

// Network libraries
#include <WiFi.h>
#include <WiFiClient.h>
#include <AsyncTCP.h>
#include <ESPAsyncWebServer.h>
#include <ElegantOTA.h>     // OTA update functionality

#if ENABLE_MQTT
#include <PubSubClient.h>   // MQTT client
#endif

// Sensor and storage libraries
#include <SPI.h>
#include <SdFat.h>          // SD card file system
#include <RTClib.h>         // Real-time clock
#include <string.h>
#include <Adafruit_ADS1X15.h> // High-precision ADC

// Optional display libraries
#if ENABLE_DISPLAY
#include <Adafruit_GFX.h>
#include <Adafruit_SSD1306.h>
#endif
#include "image_data.h"     // For display images (if enabled)

// ===== CONFIGURATION =====
// Display settings
#if ENABLE_DISPLAY
#define SCREEN_WIDTH 128    // OLED display width, in pixels
#define SCREEN_HEIGHT 64    // OLED display height, in pixels
#define OLED_RESET     -1   // Reset pin # (or -1 if sharing Arduino reset pin)
#define SCREEN_ADDRESS 0x3C // See datasheet for Address; 0x3D for 128x64, 0x3C for 128x32
#endif

// Calibration values
#define SHUNT_SIZE 100.000  // Current shunt rating: 100A / 75mV

// Direction constants
#define LEFT 1
#define RIGHT 0

// ADC settings
#define INPUT_PIN 32        // Analog input pin (if using ESP32 ADC)

// SD card settings
const int chipSelect = 15;  // SD card chip select pin

// MQTT settings
#if ENABLE_MQTT
const char* mqtt_server = MQTT_SERVER;   // From secrets.h
const int mqtt_port = MQTT_PORT;         // From secrets.h
const char* mqtt_user = MQTT_USER;       // From secrets.h
const char* mqtt_pass = MQTT_PASS;       // From secrets.h
const char* mqtt_client_id = "ESP32_BatteryMonitor";
const char* mqtt_topic_current = "battery/data/current";
const char* mqtt_topic_voltage = "battery/data/voltage";
const char* mqtt_topic_status = "battery/status";
#endif

// Timing settings
const unsigned long WIFI_RETRY_INTERVAL = 60000;  // Try to reconnect WiFi every minute
const unsigned long WIFI_CONNECT_TIMEOUT = 10000; // 10 seconds timeout for WiFi connection

// ===== OBJECT INITIALIZATION =====
Adafruit_ADS1115 ads;       // 16-bit ADC object
RTC_DS3231 rtc;             // Real-time clock object
SdFat sd;                   // SD card filesystem
SdFile file;                // File object for writing
AsyncWebServer server(80);  // Web server for OTA updates and file access

#if ENABLE_MQTT
WiFiClient espClient;       // WiFi client for MQTT
PubSubClient mqtt(espClient); // MQTT client
#endif

#if ENABLE_DISPLAY
Adafruit_SSD1306 display(SCREEN_WIDTH, SCREEN_HEIGHT, &Wire, OLED_RESET);
#endif

// ===== GLOBAL VARIABLES =====
// OTA update variables
unsigned long ota_progress_millis = 0;

// Battery monitoring variables
float current = 0.0;
int direction = RIGHT;
int direction_before = LEFT;
int direct_log = 0;
int count = 0;
int i = 1;

// Connection state variables
bool wifi_connected = false;
unsigned long last_wifi_attempt = 0;

// SD card monitoring
unsigned long last_sd_check = 0;
bool sd_initialized = false;
unsigned long last_data_written = 0;

// ===== FUNCTION DECLARATIONS =====
// OTA callback functions
void onOTAStart();
void onOTAProgress(size_t current, size_t final);
void onOTAEnd(bool success);

// Data collection and storage functions
float get_adc_data_in_A();    // Get current reading in Amperes
float get_adc_data_in_V();    // Get voltage reading in Volts
void write_file(float data, int count, String filename); // Log data to SD card
#if SD_CARD_TEST_MODE
void test_sd_card_write();    // Test function for basic SD card writing
#endif

// WiFi and MQTT functions
void check_wifi_connection();            // Check and attempt to reconnect WiFi

#if ENABLE_MQTT
bool connect_mqtt();                     // Connect to MQTT broker
void publish_data_point(float current, float voltage, DateTime timestamp); // Publish single data point
#endif

// Web server functions
void setup_web_server();                 // Setup web server routes
String list_files(String path);          // List all files in directory
String get_file_size(size_t bytes);   // Get file size as string

// Display functions
#if ENABLE_DISPLAY
void interface(float amps, int dir);  // Update display interface
void move_arrow(int dir, float amps); // Animate the direction arrow
#endif

// SD card functions
bool init_sd_card();
bool check_sd_card();

// ===== OTA CALLBACK IMPLEMENTATIONS =====
/**
 * Called when OTA update begins
 */
void onOTAStart() {
  Serial.println("OTA update started!");
}

/**
 * Called periodically during OTA update process
 */
void onOTAProgress(size_t current, size_t final) {
  // Log progress every 1 second
  if (millis() - ota_progress_millis > 1000) {
    ota_progress_millis = millis();
    Serial.printf("OTA Progress: %u of %u bytes (%.1f%%)\n", 
                 current, final, (current * 100.0) / final);
  }
}

/**
 * Called when OTA update completes
 */
void onOTAEnd(bool success) {
  if (success) {
    Serial.println("OTA update completed successfully!");
  } else {
    Serial.println("Error during OTA update!");
  }
}

#if SD_CARD_TEST_MODE
/**
 * Simple test function to verify SD card writing is working
 * Just writes zeros to a test file every second
 */
void test_sd_card_write() {
  static unsigned long lastWrite = 0;
  static int counter = 0;
  
  // Write a value every second
  if (millis() - lastWrite >= 1000) {
    lastWrite = millis();
    counter++;
    
    // Create a simple test file
    const char* testFileName = "SDTEST.TXT";
    
    Serial.print("Writing to test file: ");
    Serial.print(testFileName);
    Serial.print(" | Counter: ");
    Serial.println(counter);
    
    // Try to open the file for writing (append mode)
    if (!file.open(testFileName, O_RDWR | O_CREAT | O_AT_END)) {
      Serial.println("ERROR: Failed to open test file for writing!");
      return;
    }
    
    // Write a simple value (just the counter)
    file.print(counter);
    file.println(", 0");
    
    // Close the file to ensure data is saved
    file.close();
    
    // Verify file exists and has data
    SdFile checkFile;
    if (checkFile.open(testFileName, O_READ)) {
      Serial.print("Test file size: ");
      Serial.print(checkFile.fileSize());
      Serial.println(" bytes");
      
      // Read and display the file contents
      Serial.println("File contents:");
      char buffer[100];
      int idx = 0;
      int c;
      
      // Read up to 100 characters or end of file
      while ((c = checkFile.read()) >= 0 && idx < sizeof(buffer) - 1) {
        buffer[idx++] = (char)c;
      }
      buffer[idx] = '\0';  // Null-terminate the string
      
      Serial.println(buffer);
      checkFile.close();
    } else {
      Serial.println("WARNING: Could not verify test file after writing!");
    }
    
    // Flash the built-in LED to indicate a write cycle
    digitalWrite(LED_BUILTIN, HIGH);
    delay(50);
    digitalWrite(LED_BUILTIN, LOW);
  }
}
#endif

// ===== SETUP FUNCTION =====
void setup() {
  // Initialize serial communication
  Serial.begin(115200);
  Serial.println("\n=== Battery Management System ===");
  Serial.println("Initializing...");

  // Set up built-in LED for write indication
  pinMode(LED_BUILTIN, OUTPUT);

  // Initialize WiFi connection
  WiFi.mode(WIFI_STA);
  WiFi.setHostname("VolvoESP32");  // Set custom device name
  check_wifi_connection();         // Initial WiFi connection attempt

  // Initialize ADS1115 ADC
  Serial.println("Initializing ADC...");
  // Set ADC gain for highest precision in our voltage range
  // GAIN_SIXTEEN: +/- 0.256V range with 0.0078125mV per bit
  ads.setGain(GAIN_SIXTEEN);

  if (!ads.begin()) {
    Serial.println("ERROR: Failed to initialize ADS1115!");
    while (1) {
      delay(100); // Halt system if ADC initialization fails
    }
  }
  Serial.println("ADC initialized successfully");

  // Initialize RTC module
  Serial.println("Initializing RTC...");
  if (!rtc.begin()) {
    Serial.println("ERROR: Couldn't find RTC!");
    while (1) {
      delay(100); // Halt system if RTC initialization fails
    }
  }

  #if UPDATE_RTC_TIME
    // Set RTC to compilation time

    // rtc.adjust(DateTime(F(__DATE__), F(__TIME__ + 1 minute))) 
    //since the codebase is getting large then we need to compensate for the build time ;)
    rtc.adjust(DateTime(F(__DATE__), F("01:41:20")));
    // rtc.adjust(DateTime(F(__DATE__), F(__TIME__)));
  #endif

  DateTime time = rtc.now();
  Serial.print("Current time: ");
  Serial.printf("%02d:%02d:%02d\n", time.hour(), time.minute(), time.second());

  // Initialize SD card
  Serial.println("Initializing SD card...");
  if (!sd.begin(chipSelect, SPI_HALF_SPEED)) {
    Serial.println("ERROR: SD card initialization failed!");
    while (1) {
      // Flash LED to indicate SD card error
      digitalWrite(LED_BUILTIN, HIGH);
      delay(100);
      digitalWrite(LED_BUILTIN, LOW);
      delay(100);
    }
  }
  Serial.println("SD card initialized successfully");

  // Check if the SD card is writable by creating a test file
  SdFile testFile;
  if (!testFile.open("SDTEST.TXT", O_RDWR | O_CREAT | O_TRUNC)) {
    Serial.println("ERROR: Cannot create test file on SD card!");
    while (1) {
      // Flash LED to indicate error
      digitalWrite(LED_BUILTIN, HIGH);
      delay(100);
      digitalWrite(LED_BUILTIN, LOW);
      delay(100);
    }
  }
  
  // Write initial test data
  testFile.println("SD card test file created at startup");
  testFile.println("Current time: " + time.timestamp(DateTime::TIMESTAMP_FULL));
  testFile.close();
  Serial.println("Test file created successfully");

  // Verify we can read the file back
  if (testFile.open("SDTEST.TXT", O_READ)) {
    size_t fileSize = testFile.fileSize();
    Serial.print("Test file size: ");
    Serial.print(fileSize);
    Serial.println(" bytes");
    testFile.close();
    
    if (fileSize == 0) {
      Serial.println("ERROR: Test file is empty - write failed!");
      while (1) {
        // Flash LED to indicate error
        digitalWrite(LED_BUILTIN, HIGH);
        delay(100);
        digitalWrite(LED_BUILTIN, LOW);
        delay(100);
      }
    }
  } else {
    Serial.println("ERROR: Could not read back test file!");
    while (1) {
      // Flash LED to indicate error
      digitalWrite(LED_BUILTIN, HIGH);
      delay(100);
      digitalWrite(LED_BUILTIN, LOW);
      delay(100);
    }
  }

  // Setup web server for file browsing and OTA updates
  setup_web_server();

#if ENABLE_MQTT
  // Setup MQTT client
  mqtt.setServer(mqtt_server, mqtt_port);
  if (wifi_connected) {
    connect_mqtt();
  }
#endif

#if ENABLE_DISPLAY
  // Initialize OLED display
  Serial.println("Initializing display...");
  if(!display.begin(SSD1306_SWITCHCAPVCC, SCREEN_ADDRESS)) {
    Serial.println("ERROR: SSD1306 display initialization failed");
  } else {
    display.clearDisplay();
    display.setTextSize(1);
    display.setTextColor(WHITE);
    display.setCursor(0, 0);
    display.println("Battery Monitor");
    display.println("Initializing...");
    display.display();
    Serial.println("Display initialized successfully");
  }
#endif

  Serial.println("Setup complete!");
#if SD_CARD_TEST_MODE
  Serial.println("RUNNING IN TEST MODE - Writing to test file every second");
#endif
}

int previous_time = 0;
int time_now = 0;

// ===== MAIN LOOP =====
void loop() {
#if SD_CARD_TEST_MODE
  // Run the simple SD card write test instead of the normal data collection
  test_sd_card_write();
  
  // Handle OTA updates if WiFi connected
  if (wifi_connected) {
    ElegantOTA.loop();
  }
  
  // Try to reconnect WiFi periodically if disconnected
  if (millis() - last_wifi_attempt > WIFI_RETRY_INTERVAL) {
    check_wifi_connection();
  }

  // A short delay to avoid hammering the loop
  delay(10);
#else
  // Handle OTA updates if WiFi connected
  if (wifi_connected) {
    ElegantOTA.loop();
  }

  // Get current date/time
  DateTime now = rtc.now();
  
  // Try to reconnect WiFi periodically if disconnected
  if (millis() - last_wifi_attempt > WIFI_RETRY_INTERVAL) {
    check_wifi_connection();
  }
  
  // Collect and log data every minute (60 samples at ~1 second intervals)
  while (count < 60) {
    //if one seconds passed then run the data logging, else wait until one second
    time_now = millis();
    if((time_now - previous_time) >= 1000){
      previous_time = millis();

      // Read voltage and current values
      float data_in_amps = get_adc_data_in_A();
      float data_in_volts = get_adc_data_in_V();
              
      // Get current time
      DateTime timestamp = rtc.now();
              
      // Display readings on serial monitor
      Serial.printf("Volts: %.2fV | Amps: %.2fA | WiFi: %s\n", 
                  data_in_volts, data_in_amps, wifi_connected ? "Connected" : "Disconnected");
              
      // Write data to SD card files
      // Files are named "Amps YYYY-MM-DD.txt" and "Volts YYYY-MM-DD.txt"
      write_file(data_in_amps, count, "Amps ");
      write_file(data_in_volts, count, "Volts ");
              
      // Send data to MQTT if connected
      #if ENABLE_MQTT
      if (wifi_connected && mqtt.connected()) {
        publish_data_point(data_in_amps, data_in_volts, timestamp);
      } else if (wifi_connected && !mqtt.connected()) {
        // Try to reconnect to MQTT if WiFi is connected but MQTT is not
        connect_mqtt();
      }
      // Keep MQTT client connection alive
      if (mqtt.connected()) {
        mqtt.loop();
      }
      #endif
              
      #if ENABLE_DISPLAY
      // Update the display with current readings
      // Determine current direction (charging or discharging)
      if (data_in_amps < 0) {
        direction = RIGHT; // Charging
      } else {
        direction = LEFT;  // Discharging
      }
                  
      // Update display interface with current values and direction
      interface(data_in_amps, direction);
      #endif
              
      count++;
    }
  }

  // Log completion of one minute cycle
  Serial.println("One minute cycle completed");
  Serial.printf("Date: %02d-%02d-%04d  Time: %02d:%02d:%02d\n", 
    now.day(), now.month(), now.year(), 
    now.hour(), now.minute(), now.second());
  
  // Reset counter for the next minute
  count = 0;
#endif
}

// ===== DATA COLLECTION FUNCTIONS =====

/**
 * Read current from ADS1115 differential input
 * @return Current in Amperes
 */
float get_adc_data_in_A() {
  int16_t results;
  
  // Conversion factor for ADS1115 with GAIN_SIXTEEN (0.0078125 mV per bit)
  const double Ampmultiplier = 0.0078125;
  
  // Read differential voltage across shunt
  results = ads.readADC_Differential_0_1();
  
  // Convert to amperes based on shunt rating (100A/75mV)
  float amps = float((results * Ampmultiplier * (SHUNT_SIZE / 75.000)));
  return amps;
}

/**
 * Read voltage from ADS1115 single-ended input
 * @return Voltage in Volts
 */
float get_adc_data_in_V() {
  int16_t results;
  
  // Conversion factor for voltage divider
  const double Voltmultiplier = 0.0002696;
  
  // Read from single-ended input (A2)
  results = ads.readADC_SingleEnded(2);
  
  // Convert to volts (includes voltage divider factor of 2)
  float volts_ = float(2 * Voltmultiplier * results) + VOLTAGE_OFFSET;
  float volts = round(volts_*10)/10;
  return volts;
}

/**
 * Write data to a file on the SD card
 * @param data The data value to write
 * @param count Current sample count (0-59)
 * @param filnamn Prefix for the filename
 */
void write_file(float data, int count, String filnamn) {
  // Get current date/time
  DateTime time = rtc.now();
   
  // Create filename with date: "Prefix YYYY-MM-DD.txt"
  String date = time.timestamp(DateTime::TIMESTAMP_DATE);
  String txt = ".txt";
  String filename_merged = filnamn + date + txt;
  
  // Convert to char array for SD library
  char filename[filename_merged.length() + 1];
  filename_merged.toCharArray(filename, sizeof(filename));
  
  // Debug output with filename and count
  Serial.print("Writing to file: ");
  Serial.print(filename);
  Serial.print(" | Value: ");
  Serial.print(data);
  Serial.print(" | Count: ");
  Serial.println(count);
  
  // Open file for append - if fails, halt with error
  if (!file.open(filename, O_RDWR | O_CREAT | O_AT_END)) {
    Serial.print("ERROR: Failed to open file for writing: ");
    Serial.println(filename);
    
    // Try again once
    if (!sd.begin(chipSelect, SPI_HALF_SPEED)) {
      Serial.println("ERROR: SD card reinit failed!");
      return;
    }
    
    // Second attempt after reinitializing
    if (!file.open(filename, O_RDWR | O_CREAT | O_AT_END)) {
      Serial.println("ERROR: Still failed to open file after SD reinit!");
      return;
    }
    
    Serial.println("File opened successfully after SD reinit");
  }
  
  // Start a new line with timestamp at the beginning of each minute
  if (count == 0) {
    // Use time format HH:MM:SS
    char timestamp[9]; // HH:MM:SS + null terminator
    sprintf(timestamp, "%02d:%02d:%02d", 
            time.hour(), time.minute(), time.second());
    
    file.println(); // Start on a new line
    file.print(timestamp);
    file.print(" --> ");
    
    Serial.print("Wrote timestamp: ");
    Serial.println(timestamp);
  }

  // Write data value with comma separator (except for last value)
  file.print(data);
  if (count < 59) {
    file.print(", ");
  } else {
    // End the line on the last sample of the minute
    file.println(); // Important - ensures the line ends properly
  }

  // Close the file to ensure data is saved
  file.close();
  
  // Verify file exists with size check (only do once per minute to save performance)
  if (count == 59) {
    SdFile checkFile;
    if (checkFile.open(filename, O_READ)) {
      Serial.print("File size: ");
      Serial.print(checkFile.fileSize());
      Serial.println(" bytes");
      checkFile.close();
    }
  }
}

/**
 * Check WiFi connection and attempt to reconnect if needed
 */
void check_wifi_connection() {
  last_wifi_attempt = millis();
  
  if (WiFi.status() != WL_CONNECTED) {
    Serial.print("Attempting to connect to WiFi... ");
    
    // Make sure we're in station mode
    WiFi.mode(WIFI_STA);
    WiFi.begin(WIFI_SSID, WIFI_PASS);
    
    // Wait up to 10 seconds for connection
    unsigned long startAttempt = millis();
    while (WiFi.status() != WL_CONNECTED && millis() - startAttempt < WIFI_CONNECT_TIMEOUT) {
      delay(500);
      Serial.print(".");
    }
    
    if (WiFi.status() == WL_CONNECTED) {
      wifi_connected = true;
      Serial.println("Connected!");
      Serial.print("IP address: ");
      Serial.println(WiFi.localIP());
      
      // Connect to MQTT broker if enabled
      #if ENABLE_MQTT
      connect_mqtt();
      #endif
    } else {
      wifi_connected = false;
      Serial.println("Failed. Will retry later.");
      WiFi.disconnect(true);
    }
  } else {
    wifi_connected = true;
  }
}
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

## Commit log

2025-03-05 adding 2*multiplier since the reference voltage is not bipolar , but rather from 0.256~to 0 V.
    Which is the 16x multiplier mode fro the ADC (ADS11155)
2025-03-05 better plotting, Charging is positive values (Blue), discharging is negative values (Red)
2025-03-05 added time print in the setup to confirm correct RTC update for debugging
    [main.cpp]
2025-03-05 Amps and Volt files are named with their date to it for easier readability and main.cpp code
2025-03-05 Massive main.cpp not tested on board yet.
    Inlucded OTA funcitonality and removed non needed gpioviewer and blynk
2025-03-05 Modify plot saving behavior and remove unused dependencies, also updating file name from Volts_vs_Amps to PlotData
2025-03-06 fixing Discharge as Capacity error in plot
2025-03-12 Add error handling and SD card monitoring features
    - Introduced a new MQTT topic for error messages.
    - Implemented SD card initialization and monitoring functions.
    - Enhanced data logging to handle SD card errors and publish relevant error messages via MQTT.
    - Improved file writing logic with error checks and verification.
    - Updated the main loop to include SD card status checks and logging behavior adjustments based on SD card availability.
    [main.cpp]
2025-03-12 Enhance MQTT logging and SD card functionality
    - Added a new MQTT topic for general log messages.
    - Implemented periodic status reporting including uptime and memory usage.
    - Enhanced SD card initialization with detailed logging and verification.
    - Improved error handling during MQTT connection attempts and SD card operations.
    - Added logging for data writing and file verification processes.
    [main.cpp]
2025-03-12 enhace web ui, manual file deletion and SD card wirting testing.
